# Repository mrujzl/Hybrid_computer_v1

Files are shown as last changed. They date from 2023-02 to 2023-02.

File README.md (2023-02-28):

# Hybrid_computer_v1
Hybrid computer for study of nonlinear dynamic systems. It was developed at Department of Radio Electronics, Brno University of Technology within the grant Development of analog computer with hybrid analog-digital components for accurate modeling of chaotic systems. This grant is realised within the project Quality Internal Grants of BUT (KInG BUT), Reg. No. CZ.02.2.69 / 0.0 / 0.0 / 19_073 / 0016948, which is financed from the OP RDE.

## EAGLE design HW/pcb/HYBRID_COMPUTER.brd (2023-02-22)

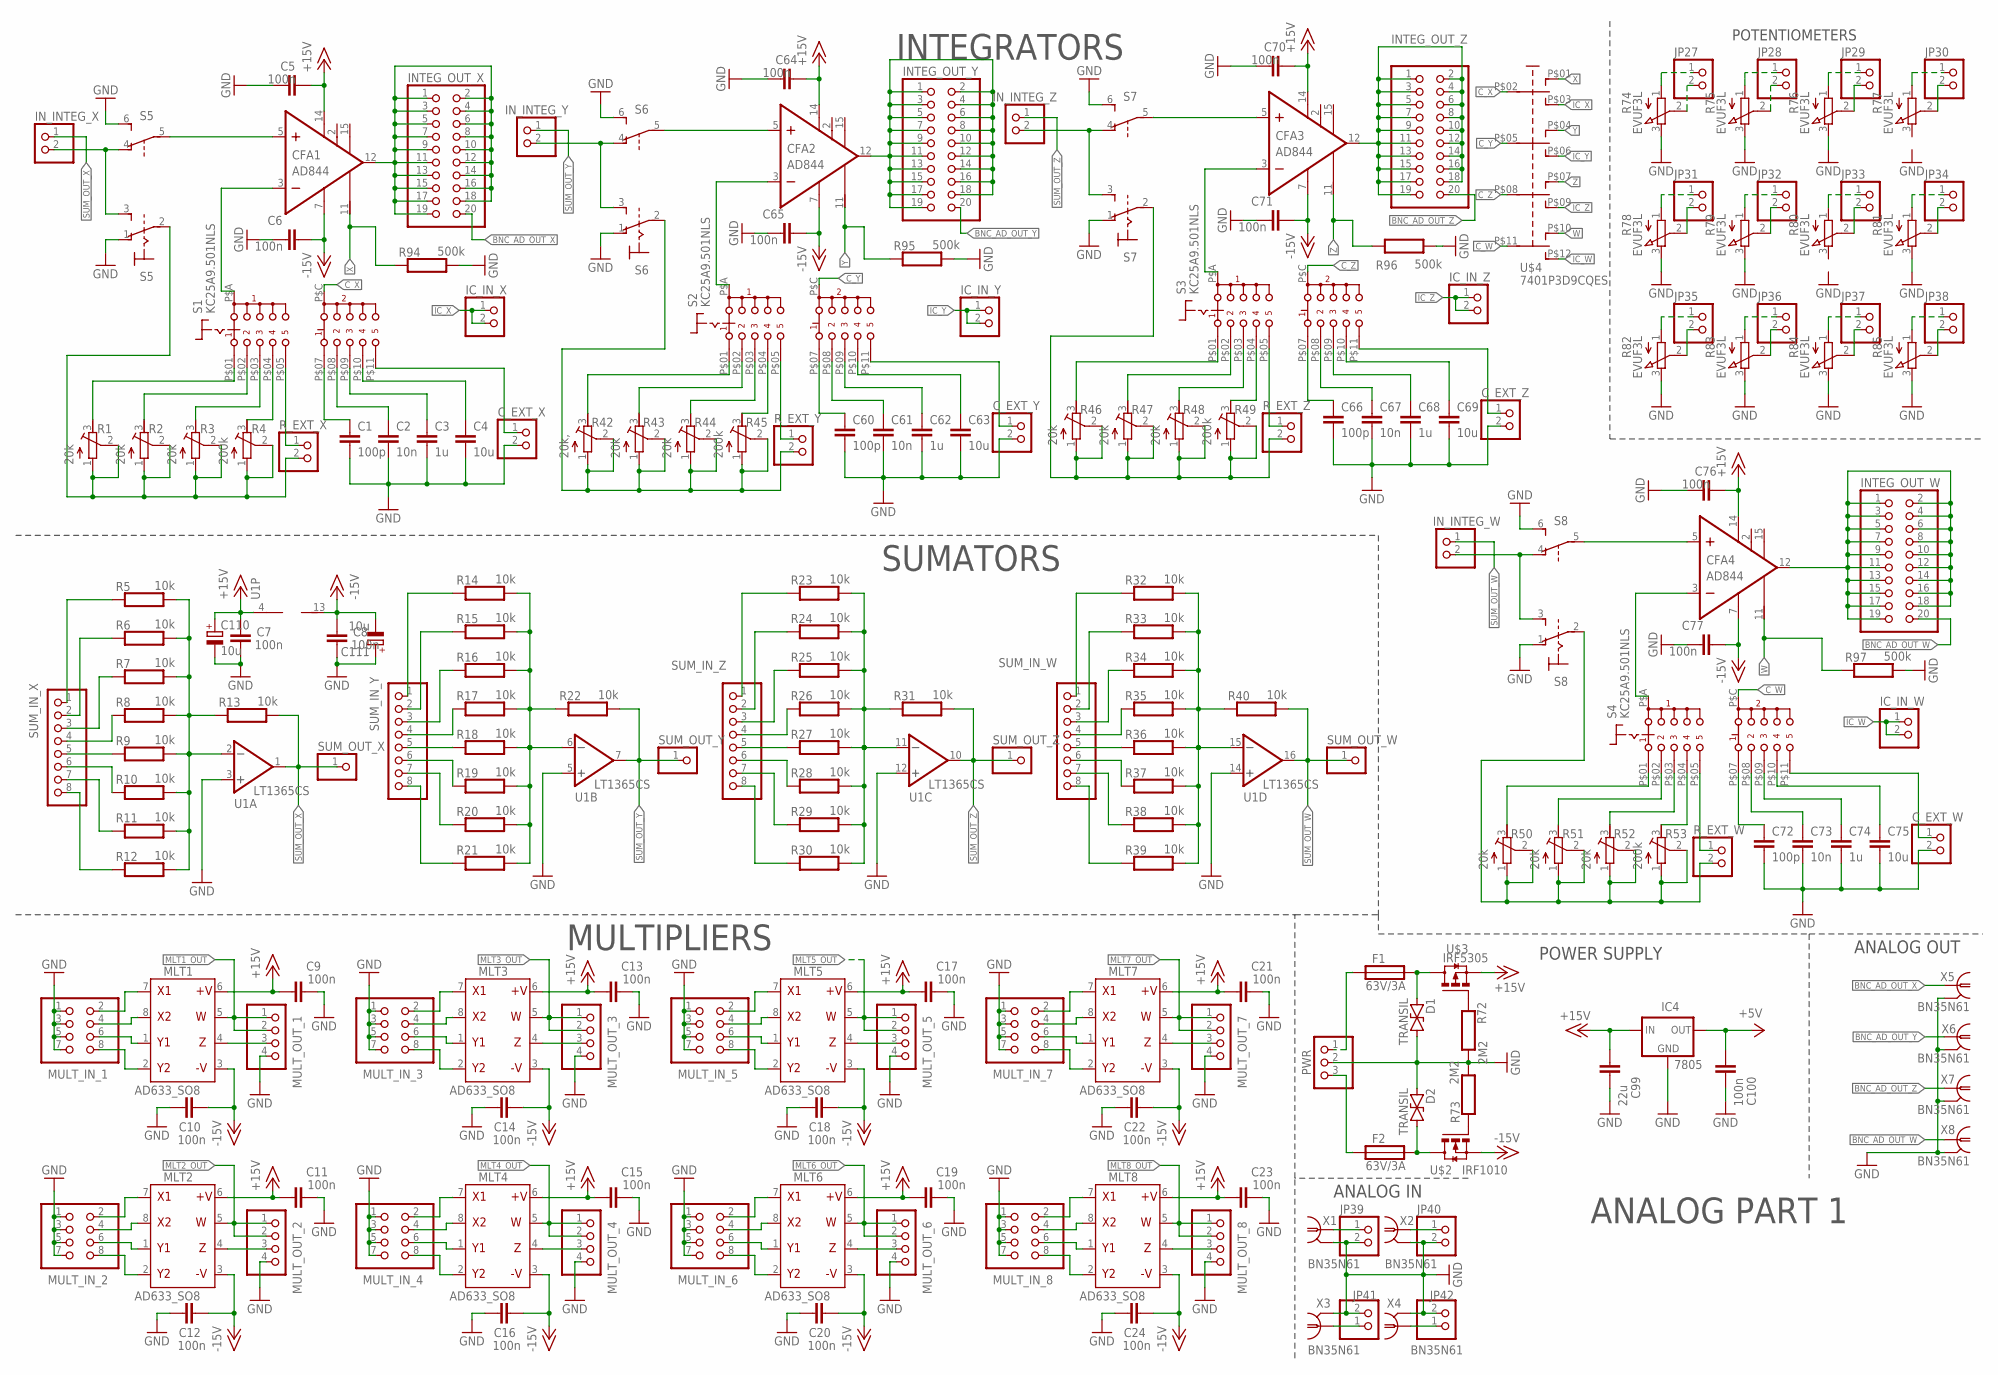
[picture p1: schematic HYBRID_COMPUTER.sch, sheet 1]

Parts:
C1, C60, C66, C72: 100p; C_1206
C2, C61, C67, C73: 10n; C_1206
C3, C62, C68, C74: 1u; C_1206
C4, C63, C69, C75: 10u; C_1206
C5, C6, C7, C8, C9, C10, C11, C12, C13, C14, C15, C16, C17, C18, C19, C20, C21, C22, C23, C24, C64, C65, C70, C71, C76, C77, C100: 100n; C_1206
C99: 22u; C_1206
C110, C111: 10u; E2,5-5
CFA1, CFA2, CFA3, CFA4: AD844; SOIC16R
C_EXT_W: PINHD-1X2; 1X02
C_EXT_X: PINHD-1X2; 1X02
C_EXT_Y: PINHD-1X2; 1X02
C_EXT_Z: PINHD-1X2; 1X02
D1, D2: TRANSIL; DO15-12
F1, F2: 63V/3A; FUSE_1206
IC4: 7805; 78MXXS
IC_IN_W: PINHD-1X2; 1X02
IC_IN_X: PINHD-1X2; 1X02
IC_IN_Y: PINHD-1X2; 1X02
IC_IN_Z: PINHD-1X2; 1X02
INTEG_OUT_W: PINHD-2X10; 2X10
INTEG_OUT_X: PINHD-2X10; 2X10
INTEG_OUT_Y: PINHD-2X10; 2X10
INTEG_OUT_Z: PINHD-2X10; 2X10
IN_INTEG_W: PINHD-1X2; 1X02
IN_INTEG_X: PINHD-1X2; 1X02
IN_INTEG_Y: PINHD-1X2; 1X02
IN_INTEG_Z: PINHD-1X2; 1X02
JP27, JP28, JP29, JP30, JP31, JP32, JP33, JP34, JP35, JP36, JP37, JP38, JP39, JP40, JP41, JP42: PINHD-1X2; 1X02
MLT1, MLT2, MLT3, MLT4, MLT5, MLT6, MLT7, MLT8: AD633_SO8; SO8
MULT_IN_1, MULT_IN_2, MULT_IN_3, MULT_IN_4, MULT_IN_5, MULT_IN_6, MULT_IN_7, MULT_IN_8: PINHD-2X4; 2X04
MULT_OUT_1, MULT_OUT_2, MULT_OUT_3, MULT_OUT_4, MULT_OUT_5, MULT_OUT_6, MULT_OUT_7, MULT_OUT_8: PINHD-1X4; 1X04
PWR: PINHD-1X3; 1X03
R1, R2, R3, R43, R44, R46, R47, R48, R50, R51, R52: 20k; RTRIM64W
R4, R45, R49, R53: 200k; RTRIM64W
R5, R6, R7, R8, R9, R10, R11, R12, R13, R14, R15, R16, R17, R18, R19, R20, R21, R22, R23, R24, R25, R26, R27, R28, R29, R30, R31, R32, R33, R34, R35, R36, R37, R38, R39, R40: 10k; R_1206
R42: 20k,; RTRIM64W
R72, R73: 2M2; R_1206
R74, R75, R76, R77, R78, R79, R80, R81, R82, R83, R84, R85: EVUF3L; EVUFXL
R94, R95, R96, R97: 500k; R_1206
R_EXT_W: PINHD-1X2; 1X02
R_EXT_X: PINHD-1X2; 1X02
R_EXT_Y: PINHD-1X2; 1X02
R_EXT_Z: PINHD-1X2; 1X02
S1, S2, S3, S4: KC25A9.501NLS
S5, S6, S7, S8: 320-938
SUM_IN_W: PINHD-1X8; 1X08
SUM_IN_X: PINHD-1X8; 1X08
SUM_IN_Y: PINHD-1X8; 1X08
SUM_IN_Z: PINHD-1X8; 1X08
SUM_OUT_W: PINHD-1X1; 1X01
SUM_OUT_X: PINHD-1X1; 1X01
SUM_OUT_Y: PINHD-1X1; 1X01
SUM_OUT_Z: PINHD-1X1; 1X01
U1: LT1365CS; SO16
U$2: IRF1010; TO220BV
U$3: IRF5305; TO220BV
U$4: 7401P3D9CQES
X1, X2, X3, X4, X5, X6, X7, X8: BN35N61; B35N61

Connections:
+5V: C100.1, IC4.OUT; also elsewhere on the board
+15V: C5.1, C7.1, C9.1, C11.1, C13.1, C15.1, C17.1, C19.1, C21.1, C23.1, C64.1, C70.1, C76.1, C99.1, C110.+, CFA1.14 (7), CFA2.14 (7), CFA3.14 (7), CFA4.14 (7), IC4.IN, MLT1.6 (8), MLT2.6 (8), MLT3.6 (8), MLT4.6 (8), MLT5.6 (8), MLT6.6 (8), MLT7.6 (8), MLT8.6 (8), U1.4 (V+), U$3.S; also elsewhere on the board
-15V: C6.1, C8.1, C10.1, C12.1, C14.1, C16.1, C18.1, C20.1, C22.1, C24.1, C65.1, C71.1, C77.1, C111.-, CFA1.7 (4), CFA2.7 (4), CFA3.7 (4), CFA4.7 (4), MLT1.3 (5), MLT2.3 (5), MLT3.3 (5), MLT4.3 (5), MLT5.3 (5), MLT6.3 (5), MLT7.3 (5), MLT8.3 (5), U1.13 (V-), U$2.S; also elsewhere on the board
BNC_AD_OUT_W: INTEG_OUT_W.20, X8.1; also elsewhere on the board
BNC_AD_OUT_X: INTEG_OUT_X.20, X5.1; also elsewhere on the board
BNC_AD_OUT_Y: INTEG_OUT_Y.20, X6.1; also elsewhere on the board
BNC_AD_OUT_Z: INTEG_OUT_Z.20, X7.1; also elsewhere on the board
C_W: S4.P$C (C), U$4.P$11 (11)
C_X: S1.P$C (C), U$4.P$02 (2)
C_Y: S2.P$C (C), U$4.P$05 (5)
C_Z: S3.P$C (C), U$4.P$08 (8)
GND: C1.2, C2.2, C3.2, C4.2, C5.2, C6.2, C7.2, C8.2, C9.2, C10.2, C11.2, C12.2, C13.2, C14.2, C15.2, C16.2, C17.2, C18.2, C19.2, C20.2, C21.2, C22.2, C23.2, C24.2, C60.2, C61.2, C62.2, C63.2, C64.2, C65.2, C66.2, C67.2, C68.2, C69.2, C70.2, C71.2, C72.2, C73.2, C74.2, C75.2, C76.2, C77.2, C99.2, C100.2, C110.-, C111.+, C_EXT_W.2, C_EXT_X.2, C_EXT_Y.2, C_EXT_Z.2, D1.C, D2.A, IC4.GND, JP39.2, JP40.2, JP41.2, JP42.2, MULT_IN_1.1, MULT_IN_1.3, MULT_IN_1.5, MULT_IN_1.7, MULT_IN_2.1, MULT_IN_2.3, MULT_IN_2.5, MULT_IN_2.7, MULT_IN_3.1, MULT_IN_3.3, MULT_IN_3.5, MULT_IN_3.7, MULT_IN_4.1, MULT_IN_4.3, MULT_IN_4.5, MULT_IN_4.7, MULT_IN_5.1, MULT_IN_5.3, MULT_IN_5.5, MULT_IN_5.7, MULT_IN_6.1, MULT_IN_6.3, MULT_IN_6.5, MULT_IN_6.7, MULT_IN_7.1, MULT_IN_7.3, MULT_IN_7.5, MULT_IN_7.7, MULT_IN_8.1, MULT_IN_8.3, MULT_IN_8.5, MULT_IN_8.7, MULT_OUT_1.4, MULT_OUT_2.4, MULT_OUT_3.4, MULT_OUT_4.4, MULT_OUT_5.4, MULT_OUT_6.4, MULT_OUT_7.4, MULT_OUT_8.4, PWR.2, R72.2, R73.2, R74.3 (E), R75.3 (E), R76.3 (E), R78.3 (E), R79.3 (E), R81.3 (E), R82.3 (E), R83.3 (E), R84.3 (E), R85.3 (E), R94.2, R95.2, R96.2, R97.2, S5.1 (O), S5.6 (S), S6.1 (O), S6.6 (S), S7.1 (O), S7.6 (S), S8.1 (O), S8.6 (S), U1.3 (+IN), U1.5 (+IN), U1.12 (+IN), U1.14 (+IN), X1.2, X1.3 (2), X1.4 (2), X1.5 (2), X2.2, X2.3 (2), X2.4 (2), X2.5 (2), X3.2, X3.3 (2), X3.4 (2), X3.5 (2), X4.2, X4.3 (2), X4.4 (2), X4.5 (2), X5.2, X5.3 (2), X5.4 (2), X5.5 (2), X6.2, X6.3 (2), X6.4 (2), X6.5 (2), X7.2, X7.3 (2), X7.4 (2), X7.5 (2), X8.2, X8.3 (2), X8.4 (2), X8.5 (2); also elsewhere on the board
IC_W: IC_IN_W.1, IC_IN_W.2, U$4.P$12 (12)
IC_X: IC_IN_X.1, IC_IN_X.2, U$4.P$03 (3)
IC_Y: IC_IN_Y.1, IC_IN_Y.2, U$4.P$06 (6)
IC_Z: IC_IN_Z.1, IC_IN_Z.2, U$4.P$09 (9)
INTEG_OUT_W: CFA4.12 (6), INTEG_OUT_W.1, INTEG_OUT_W.2, INTEG_OUT_W.3, INTEG_OUT_W.4, INTEG_OUT_W.5, INTEG_OUT_W.6, INTEG_OUT_W.7, INTEG_OUT_W.8, INTEG_OUT_W.9, INTEG_OUT_W.10, INTEG_OUT_W.11, INTEG_OUT_W.12, INTEG_OUT_W.13, INTEG_OUT_W.14, INTEG_OUT_W.15, INTEG_OUT_W.16, INTEG_OUT_W.17, INTEG_OUT_W.18, INTEG_OUT_W.19
INTEG_OUT_Y: CFA2.12 (6), INTEG_OUT_Y.1, INTEG_OUT_Y.2, INTEG_OUT_Y.3, INTEG_OUT_Y.4, INTEG_OUT_Y.5, INTEG_OUT_Y.6, INTEG_OUT_Y.7, INTEG_OUT_Y.8, INTEG_OUT_Y.9, INTEG_OUT_Y.10, INTEG_OUT_Y.11, INTEG_OUT_Y.12, INTEG_OUT_Y.13, INTEG_OUT_Y.14, INTEG_OUT_Y.15, INTEG_OUT_Y.16, INTEG_OUT_Y.17, INTEG_OUT_Y.18, INTEG_OUT_Y.19
INTEG_OUT_Z: CFA3.12 (6), INTEG_OUT_Z.1, INTEG_OUT_Z.2, INTEG_OUT_Z.3, INTEG_OUT_Z.4, INTEG_OUT_Z.5, INTEG_OUT_Z.6, INTEG_OUT_Z.7, INTEG_OUT_Z.8, INTEG_OUT_Z.9, INTEG_OUT_Z.10, INTEG_OUT_Z.11, INTEG_OUT_Z.12, INTEG_OUT_Z.13, INTEG_OUT_Z.14, INTEG_OUT_Z.15, INTEG_OUT_Z.16, INTEG_OUT_Z.17, INTEG_OUT_Z.18, INTEG_OUT_Z.19
MLT1_OUT: MLT1.5 (7), MULT_OUT_1.1, MULT_OUT_1.2
MLT2_OUT: MLT2.5 (7), MULT_OUT_2.1, MULT_OUT_2.2
MLT3_OUT: MLT3.5 (7), MULT_OUT_3.1, MULT_OUT_3.2
MLT4_OUT: MLT4.5 (7), MULT_OUT_4.1, MULT_OUT_4.2
MLT5_OUT: MLT5.5 (7), MULT_OUT_5.1, MULT_OUT_5.2
MLT6_OUT: MLT6.5 (7), MULT_OUT_6.1, MULT_OUT_6.2
MLT7_OUT: MLT7.5 (7), MULT_OUT_7.1, MULT_OUT_7.2
MLT8_OUT: MLT8.5 (7), MULT_OUT_8.1, MULT_OUT_8.2
unnamed: R1.1 (A), R1.2 (S), R2.1 (A), R2.2 (S), R3.1 (A), R3.2 (S), R4.1 (A), R4.2 (S), R_EXT_X.2, S5.2
unnamed: CFA1.5 (3), S5.5
unnamed: CFA1.3 (2), S1.P$A (A)
unnamed: IN_INTEG_X.2, S5.3 (S), S5.4 (O)
unnamed: R4.3 (E), S1.P$04 (4)
unnamed: R1.3 (E), S1.P$01 (1)
unnamed: R2.3 (E), S1.P$02 (2)
unnamed: R3.3 (E), S1.P$03 (3)
unnamed: C1.1, S1.P$07 (7)
unnamed: R5.2, R6.2, R7.2, R8.2, R9.2, R10.2, R11.2, R12.2, R13.1, U1.2 (-IN)
unnamed: C4.1, S1.P$10 (10)
unnamed: C3.1, S1.P$09 (9)
unnamed: C2.1, S1.P$08 (8)
unnamed: R_EXT_X.1, S1.P$05 (5)
unnamed: R9.1, SUM_IN_X.5
unnamed: C_EXT_X.1, S1.P$11 (11)
unnamed: R10.1, SUM_IN_X.6
unnamed: R11.1, SUM_IN_X.7
unnamed: R12.1, SUM_IN_X.8
unnamed: R8.1, SUM_IN_X.4
unnamed: R7.1, SUM_IN_X.3
unnamed: R6.1, SUM_IN_X.2
unnamed: R5.1, SUM_IN_X.1
unnamed: R14.2, R15.2, R16.2, R17.2, R18.2, R19.2, R20.2, R21.2, R22.1, U1.6 (-IN)
unnamed: JP29.2, R76.2 (S)
unnamed: R18.1, SUM_IN_Y.5
unnamed: R19.1, SUM_IN_Y.6
unnamed: R20.1, SUM_IN_Y.7
unnamed: R21.1, SUM_IN_Y.8
unnamed: R17.1, SUM_IN_Y.4
unnamed: R16.1, SUM_IN_Y.3
unnamed: R15.1, SUM_IN_Y.2
unnamed: R14.1, SUM_IN_Y.1
unnamed: R23.2, R24.2, R25.2, R26.2, R27.2, R28.2, R29.2, R30.2, R31.1, U1.11 (-IN)
unnamed: MLT1.7 (1), MULT_IN_1.2
unnamed: R27.1, SUM_IN_Z.5
unnamed: R28.1, SUM_IN_Z.6
unnamed: R29.1, SUM_IN_Z.7
unnamed: R30.1, SUM_IN_Z.8
unnamed: R26.1, SUM_IN_Z.4
unnamed: R25.1, SUM_IN_Z.3
unnamed: R24.1, SUM_IN_Z.2
unnamed: R23.1, SUM_IN_Z.1
unnamed: R32.2, R33.2, R34.2, R35.2, R36.2, R37.2, R38.2, R39.2, R40.1, U1.15 (-IN)
unnamed: R36.1, SUM_IN_W.5
unnamed: R37.1, SUM_IN_W.6
unnamed: R38.1, SUM_IN_W.7
unnamed: R39.1, SUM_IN_W.8
unnamed: R35.1, SUM_IN_W.4
unnamed: R34.1, SUM_IN_W.3
unnamed: R33.1, SUM_IN_W.2
unnamed: R32.1, SUM_IN_W.1
unnamed: MLT1.4 (6), MULT_OUT_1.3
unnamed: MLT1.8 (2), MULT_IN_1.4
unnamed: MLT1.1 (3), MULT_IN_1.6
unnamed: MLT1.2 (4), MULT_IN_1.8
unnamed: MLT2.4 (6), MULT_OUT_2.3
unnamed: MLT2.7 (1), MULT_IN_2.2
unnamed: MLT2.8 (2), MULT_IN_2.4
unnamed: MLT2.1 (3), MULT_IN_2.6
unnamed: MLT2.2 (4), MULT_IN_2.8
unnamed: MLT3.4 (6), MULT_OUT_3.3
unnamed: MLT3.7 (1), MULT_IN_3.2
unnamed: MLT3.8 (2), MULT_IN_3.4
unnamed: MLT3.1 (3), MULT_IN_3.6
unnamed: MLT3.2 (4), MULT_IN_3.8
unnamed: R46.1 (A), R46.2 (S), R47.1 (A), R47.2 (S), R48.1 (A), R48.2 (S), R49.1 (A), R49.2 (S), R_EXT_Z.2, S7.2
unnamed: MLT4.4 (6), MULT_OUT_4.3
unnamed: MLT4.7 (1), MULT_IN_4.2
unnamed: MLT4.8 (2), MULT_IN_4.4
unnamed: MLT4.1 (3), MULT_IN_4.6
unnamed: MLT4.2 (4), MULT_IN_4.8
unnamed: MLT5.4 (6), MULT_OUT_5.3
unnamed: MLT5.7 (1), MULT_IN_5.2
unnamed: MLT5.8 (2), MULT_IN_5.4
unnamed: MLT5.1 (3), MULT_IN_5.6
unnamed: MLT5.2 (4), MULT_IN_5.8
unnamed: MLT6.4 (6), MULT_OUT_6.3
unnamed: MLT6.7 (1), MULT_IN_6.2
unnamed: MLT6.8 (2), MULT_IN_6.4
unnamed: MLT6.1 (3), MULT_IN_6.6
unnamed: MLT6.2 (4), MULT_IN_6.8
unnamed: MLT7.4 (6), MULT_OUT_7.3
unnamed: MLT7.7 (1), MULT_IN_7.2
unnamed: MLT7.8 (2), MULT_IN_7.4
unnamed: MLT7.1 (3), MULT_IN_7.6
unnamed: MLT7.2 (4), MULT_IN_7.8
unnamed: MLT8.4 (6), MULT_OUT_8.3
unnamed: MLT8.7 (1), MULT_IN_8.2
unnamed: MLT8.8 (2), MULT_IN_8.4
unnamed: MLT8.1 (3), MULT_IN_8.6
unnamed: MLT8.2 (4), MULT_IN_8.8
unnamed: JP27.1, R74.1 (A)
unnamed: JP27.2, R74.2 (S)
unnamed: JP28.2, R75.2 (S)
unnamed: JP28.1, R75.1 (A)
unnamed: JP29.1, R76.1 (A)
unnamed: JP30.1, R77.1 (A)
unnamed: JP30.2, R77.2 (S)
unnamed: JP34.1, R81.1 (A)
unnamed: JP34.2, R81.2 (S)
unnamed: JP33.2, R80.2 (S)
unnamed: JP33.1, R80.1 (A)
unnamed: JP32.1, R79.1 (A)
unnamed: JP32.2, R79.2 (S)
unnamed: JP31.1, R78.1 (A)
unnamed: JP31.2, R78.2 (S)
unnamed: JP35.1, R82.1 (A)
unnamed: JP35.2, R82.2 (S)
unnamed: JP36.1, R83.1 (A)
unnamed: JP36.2, R83.2 (S)
unnamed: JP37.1, R84.1 (A)
unnamed: JP37.2, R84.2 (S)
unnamed: JP38.1, R85.1 (A)
unnamed: JP38.2, R85.2 (S)
unnamed: D1.A, F1.2, U$3.D
unnamed: R42.1 (A), R42.2 (S), R43.1 (A), R43.2 (S), R44.1 (A), R44.2 (S), R45.1 (A), R45.2 (S), R_EXT_Y.2, S6.2
unnamed: CFA2.5 (3), S6.5
unnamed: CFA2.3 (2), S2.P$A (A)
unnamed: IN_INTEG_Y.2, S6.3 (S), S6.4 (O)
unnamed: R42.3 (E), S2.P$01 (1)
unnamed: R43.3 (E), S2.P$02 (2)
unnamed: R44.3 (E), S2.P$03 (3)
unnamed: C63.1, S2.P$10 (10)
unnamed: C62.1, S2.P$09 (9)
unnamed: C61.1, S2.P$08 (8)
unnamed: CFA1.12 (6), INTEG_OUT_X.1, INTEG_OUT_X.2, INTEG_OUT_X.3, INTEG_OUT_X.4, INTEG_OUT_X.5, INTEG_OUT_X.6, INTEG_OUT_X.7, INTEG_OUT_X.8, INTEG_OUT_X.9, INTEG_OUT_X.10, INTEG_OUT_X.11, INTEG_OUT_X.12, INTEG_OUT_X.13, INTEG_OUT_X.14, INTEG_OUT_X.15, INTEG_OUT_X.16, INTEG_OUT_X.17, INTEG_OUT_X.18, INTEG_OUT_X.19
unnamed: R45.3 (E), S2.P$04 (4)
unnamed: C60.1, S2.P$07 (7)
unnamed: R_EXT_Y.1, S2.P$05 (5)
unnamed: C_EXT_Y.1, S2.P$11 (11)
unnamed: CFA3.5 (3), S7.5
unnamed: CFA3.3 (2), S3.P$A (A)
unnamed: IN_INTEG_Z.2, S7.3 (S), S7.4 (O)
unnamed: R46.3 (E), S3.P$01 (1)
unnamed: R47.3 (E), S3.P$02 (2)
unnamed: R48.3 (E), S3.P$03 (3)
unnamed: C69.1, S3.P$10 (10)
unnamed: C68.1, S3.P$09 (9)
unnamed: C67.1, S3.P$08 (8)
unnamed: R49.3 (E), S3.P$04 (4)
unnamed: C66.1, S3.P$07 (7)
unnamed: R_EXT_Z.1, S3.P$05 (5)
unnamed: C_EXT_Z.1, S3.P$11 (11)
unnamed: R50.1 (A), R50.2 (S), R51.1 (A), R51.2 (S), R52.1 (A), R52.2 (S), R53.1 (A), R53.2 (S), R_EXT_W.2, S8.2
unnamed: CFA4.5 (3), S8.5
unnamed: CFA4.3 (2), S4.P$A (A)
unnamed: IN_INTEG_W.2, S8.3 (S), S8.4 (O)
unnamed: R50.3 (E), S4.P$01 (1)
unnamed: R51.3 (E), S4.P$02 (2)
unnamed: R52.3 (E), S4.P$03 (3)
unnamed: C75.1, S4.P$10 (10)
unnamed: C74.1, S4.P$09 (9)
unnamed: C73.1, S4.P$08 (8)
unnamed: R53.3 (E), S4.P$04 (4)
unnamed: C72.1, S4.P$07 (7)
unnamed: R_EXT_W.1, S4.P$05 (5)
unnamed: C_EXT_W.1, S4.P$11 (11)
unnamed: F2.1, PWR.3
unnamed: F1.1, PWR.1
unnamed: JP39.1, X1.1
unnamed: JP40.1, X2.1
unnamed: JP41.1, X3.1
unnamed: JP42.1, X4.1
unnamed: D2.C, F2.2, U$2.D
unnamed: R72.1, U$3.G
unnamed: R73.1, U$2.G
SUM_OUT_W: IN_INTEG_W.1, R40.2, SUM_OUT_W.1, U1.16 (OUT)
SUM_OUT_X: IN_INTEG_X.1, R13.2, SUM_OUT_X.1, U1.1 (OUT)
SUM_OUT_Y: IN_INTEG_Y.1, R22.2, SUM_OUT_Y.1, U1.7 (OUT)
SUM_OUT_Z: IN_INTEG_Z.1, R31.2, SUM_OUT_Z.1, U1.10 (OUT)
W: CFA4.11 (5), R97.1, U$4.P$10 (10)
X: CFA1.11 (5), R94.1, U$4.P$01 (1)
Y: CFA2.11 (5), R95.1, U$4.P$04 (4)
Z: CFA3.11 (5), R96.1, U$4.P$07 (7)

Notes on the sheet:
ANALOG PART 1
INTEGRATORS
ANALOG OUT
SUMATORS
POWER SUPPLY
MULTIPLIERS
POTENTIOMETERS
ANALOG IN

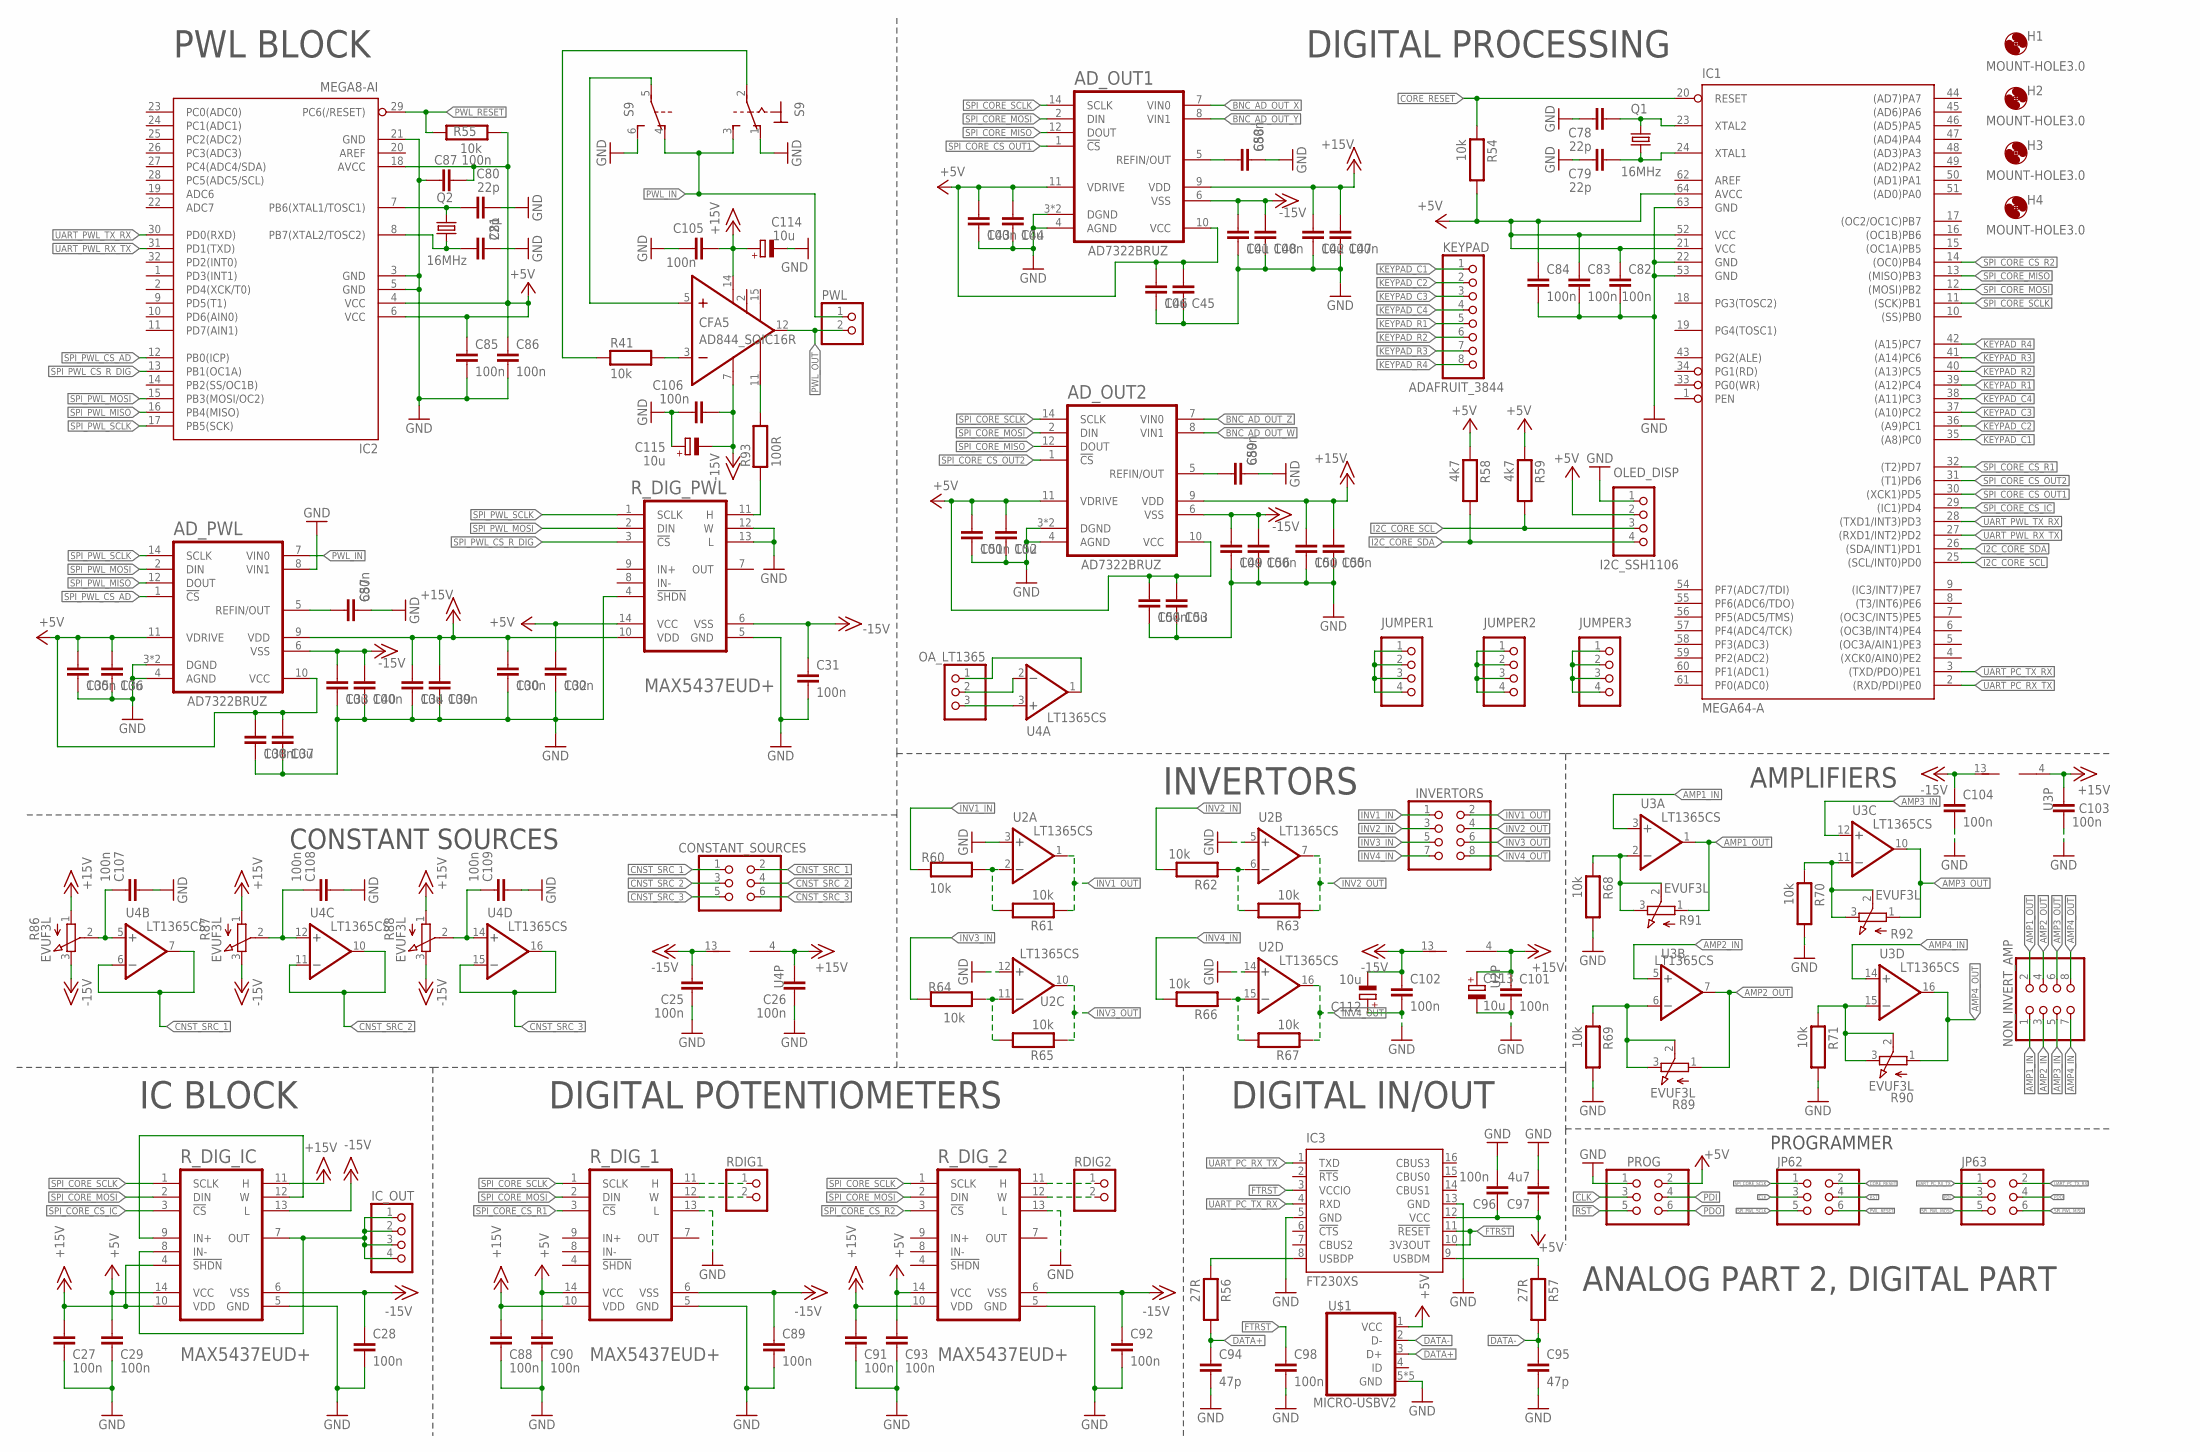
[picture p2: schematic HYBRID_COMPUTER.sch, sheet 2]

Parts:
AD_OUT1, AD_OUT2: AD7322; TSSOP-14
AD_PWL: AD7322; TSSOP-14
C25, C26, C27, C28, C29, C30, C31, C32, C35, C38, C39, C40, C43, C47, C48, C51, C54, C55, C56, C82, C83, C84, C85, C86, C87, C88, C89, C90, C91, C92, C93, C96, C98, C101, C102, C103, C104, C105, C106, C107, C108, C109: 100n; C_1206
C33, C34, C36, C37, C41, C42, C44, C46, C49, C50, C52, C53: 10u; C_1206
C45: C_1206
C57, C58, C59: 680n; C_1206
C78, C79, C80, C81: 22p; C_1206
C94, C95: 47p; C_1206
C97: 4u7; C_1206
C112, C113, C114, C115: 10u; E2,5-5
CFA5: AD844_SOIC16R; SOIC16R
CONSTANT_SOURCES: PINHD-2X3; 2X03
H1, H2, H3, H4: MOUNT-HOLE3.0; 3,0
IC1: MEGA64-A; TQFP64
IC2: MEGA8-AI; TQFP32-08
IC3: FT230XS; SSOP16
IC_OUT: PINHD-1X4; 1X04
INVERTORS: PINHD-2X4; 2X04
JP62, JP63: PINHD-2X3; 2X03
JUMPER1, JUMPER2, JUMPER3: PINHD-1X4; 1X04
KEYPAD: ADAFRUIT_3844; 1X08
NON_INVERT_AMP: PINHD-2X4; 2X04
OA_LT1365: PINHD-1X3; 1X03
OLED_DISP: I2C_SSH1106; 1X04
PROG: PINHD-2X3; 2X03
PWL: PINHD-1X2; 1X02
Q1, Q2: 16MHz; HC49/S
R41, R54, R55, R60, R61, R62, R63, R64, R65, R66, R67, R68, R69, R70, R71: 10k; R_1206
R56, R57: 27R; R_1206
R58, R59: 4k7; R_1206
R86, R87, R88, R89, R90, R91, R92: EVUF3L; EVUFXL
R93: 100R; R_1206
RDIG1, RDIG2: PINHD-1X2; 1X02
R_DIG_1, R_DIG_2: MAXIM_MAX5437EUD+MAXIM_MAX5437EUD+_0_0; MAXIM_MAX5437EUD+_0
R_DIG_IC: MAXIM_MAX5437EUD+MAXIM_MAX5437EUD+_0_0; MAXIM_MAX5437EUD+_0
R_DIG_PWL: MAXIM_MAX5437EUD+MAXIM_MAX5437EUD+_0_0; MAXIM_MAX5437EUD+_0
S9: 320-938
U2, U3, U4: LT1365CS; SO16
U$1: MICRO-USBV2; MICRO-USB-2

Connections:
+5V: AD_OUT1.10 (VCC), AD_OUT1.11 (VDRIVE), AD_OUT2.10 (VCC), AD_OUT2.11 (VDRIVE), AD_PWL.10 (VCC), AD_PWL.11 (VDRIVE), C29.1, C32.1, C35.1, C36.1, C37.1, C38.1, C43.1, C44.1, C45.1, C46.1, C51.1, C52.1, C53.1, C54.1, C82.1, C83.1, C84.1, C85.1, C86.1, C87.1, C90.1, C93.1, C96.1, C97.1, IC1.21 (VCC), IC1.52 (VCC), IC1.64 (AVCC), IC2.4 (VCC), IC2.6 (VCC), IC2.18 (AVCC), IC3.12 (VCC), OLED_DISP.2, PROG.2, R54.2, R55.2, R58.1, R59.1, R_DIG_1.14 (VCC), R_DIG_2.14 (VCC), R_DIG_IC.14 (VCC), R_DIG_PWL.14 (VCC), U$1.1 (VCC); also elsewhere on the board
+15V: AD_OUT1.9 (VDD), AD_OUT2.9 (VDD), AD_PWL.9 (VDD), C26.2, C27.1, C30.1, C34.1, C39.1, C42.1, C47.1, C50.1, C55.1, C88.1, C91.1, C101.1, C103.1, C105.1, C113.+, C114.+, CFA5.14 (7), R86.1 (A), R87.1 (A), R88.1 (A), R_DIG_1.10 (VDD), R_DIG_2.10 (VDD), R_DIG_IC.4 (!SHDN!), R_DIG_IC.10 (VDD), R_DIG_IC.11 (H), R_DIG_PWL.10 (VDD), U2.4 (V+), U3.4 (V+), U4.4 (V+); also elsewhere on the board
-15V: AD_OUT1.6 (VSS), AD_OUT2.6 (VSS), AD_PWL.6 (VSS), C25.2, C28.1, C31.1, C33.1, C40.1, C41.1, C48.1, C49.1, C56.1, C89.1, C92.1, C102.1, C104.1, C106.1, C112.-, C115.-, CFA5.7 (4), R86.3 (E), R87.3 (E), R88.3 (E), R_DIG_1.6 (VSS), R_DIG_2.6 (VSS), R_DIG_IC.6 (VSS), R_DIG_IC.13 (L), R_DIG_PWL.6 (VSS), U2.13 (V-), U3.13 (V-), U4.13 (V-); also elsewhere on the board
AMP1_IN: NON_INVERT_AMP.1, U3.3 (+IN)
AMP1_OUT: NON_INVERT_AMP.2, R91.1 (A), U3.1 (OUT)
AMP2_IN: NON_INVERT_AMP.3, U3.5 (+IN)
AMP2_OUT: NON_INVERT_AMP.4, R89.1 (A), U3.7 (OUT)
AMP3_IN: NON_INVERT_AMP.5, U3.12 (+IN)
AMP3_OUT: NON_INVERT_AMP.6, R92.1 (A), U3.10 (OUT)
AMP4_IN: NON_INVERT_AMP.7, U3.14 (+IN)
AMP4_OUT: NON_INVERT_AMP.8, R90.1 (A), U3.16 (OUT)
BNC_AD_OUT_W: AD_OUT2.8 (VIN1); also elsewhere on the board
BNC_AD_OUT_X: AD_OUT1.7 (VIN0); also elsewhere on the board
BNC_AD_OUT_Y: AD_OUT1.8 (VIN1); also elsewhere on the board
BNC_AD_OUT_Z: AD_OUT2.7 (VIN0); also elsewhere on the board
CLK: JP62.3, PROG.3
CNST_SRC_1: CONSTANT_SOURCES.1, CONSTANT_SOURCES.2, U4.6 (-IN), U4.7 (OUT)
CNST_SRC_2: CONSTANT_SOURCES.3, CONSTANT_SOURCES.4, U4.10 (OUT), U4.11 (-IN)
CNST_SRC_3: CONSTANT_SOURCES.5, CONSTANT_SOURCES.6, U4.15 (-IN), U4.16 (OUT)
CORE_RESET: IC1.20 (RESET), JP62.2, R54.1
DATA+: C94.1, R56.2, U$1.3 (D+)
DATA-: C95.1, R57.2, U$1.2 (D-)
FTRST: C98.1, IC3.3 (VCCIO), IC3.10 (3V3OUT), IC3.11 (!RESET)
GND: AD_OUT1.3 (DGND), AD_OUT1.4 (AGND), AD_OUT1.13 (DGND), AD_OUT2.3 (DGND), AD_OUT2.4 (AGND), AD_OUT2.13 (DGND), AD_PWL.3 (DGND), AD_PWL.4 (AGND), AD_PWL.8 (VIN1), AD_PWL.13 (DGND), C25.1, C26.1, C27.2, C28.2, C29.2, C30.2, C31.2, C32.2, C33.2, C34.2, C35.2, C36.2, C37.2, C38.2, C39.2, C40.2, C41.2, C42.2, C43.2, C44.2, C45.2, C46.2, C47.2, C48.2, C49.2, C50.2, C51.2, C52.2, C53.2, C54.2, C55.2, C56.2, C57.2, C58.2, C59.2, C78.1, C79.1, C80.2, C81.2, C82.2, C83.2, C84.2, C85.2, C86.2, C87.2, C88.2, C89.2, C90.2, C91.2, C92.2, C93.2, C94.2, C95.2, C96.2, C97.2, C98.2, C101.2, C102.2, C103.2, C104.2, C105.2, C106.2, C107.2, C108.2, C109.2, C112.+, C113.-, C114.-, C115.+, IC1.22 (GND), IC1.53 (GND), IC1.63 (GND), IC2.3 (GND), IC2.5 (GND), IC2.21 (GND), IC3.5 (GND), IC3.13 (GND), OLED_DISP.1, PROG.1, R68.2, R69.2, R70.2, R71.2, R_DIG_1.5 (GND), R_DIG_1.13 (L), R_DIG_2.5 (GND), R_DIG_2.13 (L), R_DIG_IC.5 (GND), R_DIG_PWL.4 (!SHDN!), R_DIG_PWL.5 (GND), R_DIG_PWL.12 (W), R_DIG_PWL.13 (L), S9.1 (O), S9.6 (S), U2.3 (+IN), U2.5 (+IN), U2.12 (+IN), U2.14 (+IN), U$1.5 (GND), U$1.P$1 (GND), U$1.P$2 (GND), U$1.P$3 (GND), U$1.P$4 (GND); also elsewhere on the board
I2C_CORE_SCL: IC1.25 ((SCL/INT0)PD0), OLED_DISP.3, R59.2
I2C_CORE_SDA: IC1.26 ((SDA/INT1)PD1), OLED_DISP.4, R58.2
INV1_IN: INVERTORS.1, R60.2
INV1_OUT: INVERTORS.2, R61.1, U2.1 (OUT)
INV2_IN: INVERTORS.3, R62.2
INV2_OUT: INVERTORS.4, R63.1, U2.7 (OUT)
INV3_IN: INVERTORS.5, R64.2
INV3_OUT: INVERTORS.6, R65.1, U2.10 (OUT)
INV4_IN: INVERTORS.7, R66.2
INV4_OUT: INVERTORS.8, R67.1, U2.16 (OUT)
KEYPAD_C1: IC1.35 ((A8)PC0), KEYPAD.1
KEYPAD_C2: IC1.36 ((A9)PC1), KEYPAD.2
KEYPAD_C3: IC1.37 ((A10)PC2), KEYPAD.3
KEYPAD_C4: IC1.38 ((A11)PC3), KEYPAD.4
KEYPAD_R1: IC1.39 ((A12)PC4), KEYPAD.5
KEYPAD_R2: IC1.40 ((A13)PC5), KEYPAD.6
KEYPAD_R3: IC1.41 ((A14)PC6), KEYPAD.7
KEYPAD_R4: IC1.42 ((A15)PC7), KEYPAD.8
unnamed: R93.1, R_DIG_PWL.11 (H)
unnamed: OA_LT1365.3, U4.3 (+IN)
unnamed: CFA5.5 (3), S9.5
unnamed: R68.1, R91.2 (S), R91.3 (E), U3.2 (-IN)
unnamed: R69.1, R89.2 (S), R89.3 (E), U3.6 (-IN)
unnamed: CFA5.3 (2), R41.2
unnamed: R41.1, S9.2
unnamed: R70.1, R92.2 (S), R92.3 (E), U3.11 (-IN)
unnamed: OA_LT1365.2, U4.2 (-IN)
unnamed: C107.1, R86.2 (S), U4.5 (+IN)
unnamed: OA_LT1365.1, U4.1 (OUT)
unnamed: R71.1, R90.2 (S), R90.3 (E), U3.15 (-IN)
unnamed: C109.1, R88.2 (S), U4.14 (+IN)
unnamed: R_DIG_IC.9 (IN+), R_DIG_IC.12 (W)
unnamed: IC_OUT.1, IC_OUT.2, IC_OUT.3, IC_OUT.4, R_DIG_IC.7 (OUT), R_DIG_IC.8 (IN-)
unnamed: C108.1, R87.2 (S), U4.12 (+IN)
unnamed: CFA5.11 (5), R93.2
unnamed: JUMPER1.1, JUMPER1.2, JUMPER1.3, JUMPER1.4
unnamed: AD_PWL.5 (REFIN/OUT), C57.1
unnamed: AD_OUT1.5 (REFIN/OUT), C58.1
unnamed: AD_OUT2.5 (REFIN/OUT), C59.1
unnamed: JUMPER2.1, JUMPER2.2, JUMPER2.3, JUMPER2.4
unnamed: JUMPER3.1, JUMPER3.2, JUMPER3.3, JUMPER3.4
unnamed: C80.1, IC2.7 (PB6(XTAL1/TOSC1)), Q2.2
unnamed: C81.1, IC2.8 (PB7(XTAL2/TOSC2)), Q2.1
unnamed: C78.2, IC1.23 (XTAL2), Q1.2
unnamed: C79.2, IC1.24 (XTAL1), Q1.1
unnamed: RDIG1.1, R_DIG_1.11 (H)
unnamed: RDIG1.2, R_DIG_1.12 (W)
unnamed: RDIG2.1, R_DIG_2.11 (H)
unnamed: RDIG2.2, R_DIG_2.12 (W)
unnamed: IC3.8 (USBDP), R56.1
unnamed: IC3.9 (USBDM), R57.1
unnamed: R60.1, R61.2, U2.2 (-IN)
unnamed: R62.1, R63.2, U2.6 (-IN)
unnamed: R66.1, R67.2, U2.15 (-IN)
unnamed: R64.1, R65.2, U2.11 (-IN)
PDI: JP63.3, PROG.4
PDO: JP63.4, PROG.6
PWL_IN: AD_PWL.7 (VIN0), PWL.1, S9.3 (S), S9.4 (O)
PWL_OUT: CFA5.12 (6), PWL.2
PWL_RESET: IC2.29 (PC6(/RESET)), JP62.6, R55.1
RST: JP62.4, PROG.5
SPI_CORE_CS_IC: IC1.29 ((IC1)PD4), R_DIG_IC.3 (!CS!)
SPI_CORE_CS_OUT1: AD_OUT1.1 (!CS!), IC1.30 ((XCK1)PD5)
SPI_CORE_CS_OUT2: AD_OUT2.1 (!CS!), IC1.31 ((T1)PD6)
SPI_CORE_CS_R1: IC1.32 ((T2)PD7), R_DIG_1.3 (!CS!)
SPI_CORE_CS_R2: IC1.14 ((OC0)PB4), R_DIG_2.3 (!CS!)
SPI_CORE_MISO: AD_OUT1.12 (DOUT), AD_OUT2.12 (DOUT), IC1.13 ((MISO)PB3)
SPI_CORE_MOSI: AD_OUT1.2 (DIN), AD_OUT2.2 (DIN), IC1.12 ((MOSI)PB2), R_DIG_1.2 (DIN), R_DIG_2.2 (DIN), R_DIG_IC.2 (DIN)
SPI_CORE_SCLK: AD_OUT1.14 (SCLK), AD_OUT2.14 (SCLK), IC1.11 ((SCK)PB1), JP62.1, R_DIG_1.1 (SCLK), R_DIG_2.1 (SCLK), R_DIG_IC.1 (SCLK)
SPI_PWL_CS_AD: AD_PWL.1 (!CS!), IC2.12 (PB0(ICP))
SPI_PWL_CS_R_DIG: IC2.13 (PB1(OC1A)), R_DIG_PWL.3 (!CS!)
SPI_PWL_MISO: AD_PWL.12 (DOUT), IC2.16 (PB4(MISO)), JP63.6
SPI_PWL_MOSI: AD_PWL.2 (DIN), IC2.15 (PB3(MOSI/OC2)), JP63.5, R_DIG_PWL.2 (DIN)
SPI_PWL_SCLK: AD_PWL.14 (SCLK), IC2.17 (PB5(SCK)), JP62.5, R_DIG_PWL.1 (SCLK)
UART_PC_RX_TX: IC1.2 ((RXD/PDI)PE0), IC3.1 (TXD), JP63.1
UART_PC_TX_RX: IC1.3 ((TXD/PDO)PE1), IC3.4 (RXD), JP63.2
UART_PWL_RX_TX: IC1.27 ((RXD1/INT2)PD2), IC2.31 (PD1(TXD))
UART_PWL_TX_RX: IC1.28 ((TXD1/INT3)PD3), IC2.30 (PD0(RXD))

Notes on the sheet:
ANALOG PART 2, DIGITAL PART
PWL BLOCK
IC BLOCK
DIGITAL PROCESSING
DIGITAL IN/OUT
CONSTANT SOURCES
PROGRAMMER
DIGITAL POTENTIOMETERS
INVERTORS
AMPLIFIERS

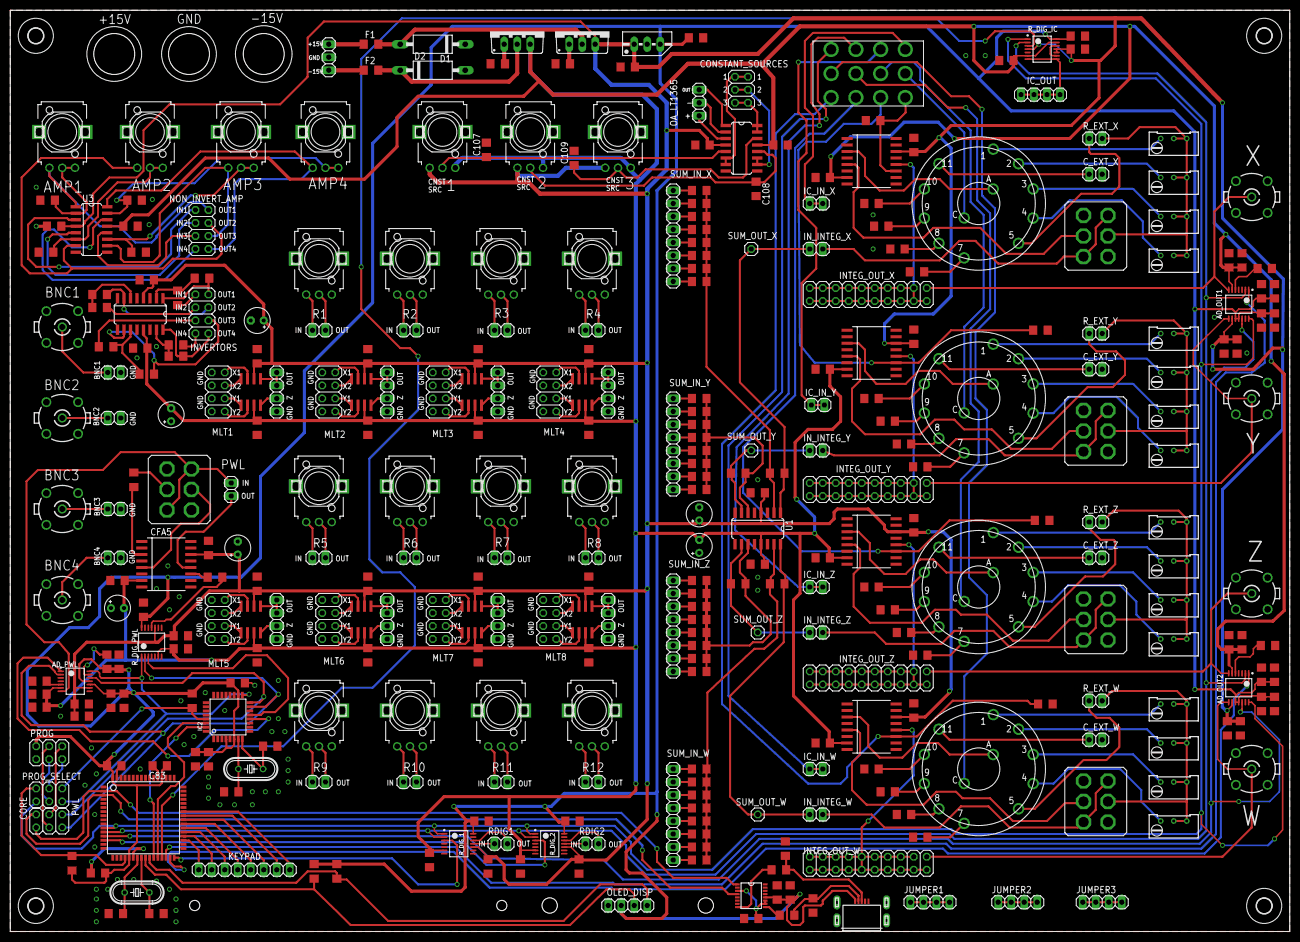
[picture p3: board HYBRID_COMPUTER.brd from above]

Board: 2 copper layers, 250.0 x 180.0 mm, 348 parts (0 on the bottom side), 296 nets.

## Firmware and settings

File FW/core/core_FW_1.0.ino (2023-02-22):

/*
      CORE_FW_1.0

   Author: Miroslav Rujzl

   This code is used for the main MCU of the hybrid computer
   for simulation and modeling of nonlinear dynamic systems.
   It was developed at Department of Radio Electronics,
   Brno University of Technology within the grant Development of
   analog computer with hybrid analog-digital components for
   accurate modeling of chaotic systems. This grant is realised
   within the project Quality Internal Grants of BUT (KInG BUT),
   Reg. No. CZ.02.2.69 / 0.0 / 0.0 / 19_073 / 0016948, which is
   financed from the OP RDE.

   Information about the board (MegaCore):
   - MCU ATMega64
   - External 16MHz crystal
   - BOD 2.7V
   - EEPROM retained
   - LTO disabled
   - No bootloader
   - Arduino as ISP (MegaCore) programmer

   Controlable components:
  ´- Keyboard ADAFRUIT 3844
   - I2C display
   - UART for communication with PC
   - 3x digital potentiometers MAX5437EUD+ (2x counting potentiometers,
     1x for initial conditions settings)
   - 2x AD converters AD7322BRUZ
   - 1x PWL block (communication via UART commands)

*/

// --- Includes ---

#include <Keypad.h>
#include "U8glib.h"
#include <SPI.h>

#include "core_fw_pinout.h"
#include "max5437eud_reg_ctrl.h"
#include "ad7322bruz_reg_ctrl.h"

// --- Defines ---

// UART settings
#define UART_PC_BAUDRATE      115200
#define UART_PWL_BAUDRATE     9600

// Display settings
#define REMOTE_DIS  0
#define REMOTE_EN   1
#define RECORD_DIS  0
#define RECORD_EN   1

// STM defines
#define STM_STATE_INIT    0
#define STM_STATE_MAIN    1
#define STM_STATE_IC      2
#define STM_STATE_RDIG    3
#define STM_STATE_PWL     4
#define STM_STATE_RECORD  5
#define STM_STATE_REMOTE  6

// Remote defines
#define REMOTE_IC         1
#define REMOTE_R1         2
#define REMOTE_R2         3
#define REMOTE_PWL        4
#define REMOTE_RECSTART   5
#define REMOTE_RECSTOP    6     

// --- Typedefs ---

typedef void (*function_p)();

// --- Global variables ---

// Keypad config
const uint8_t   rows = 4;
const uint8_t   columns = 4;
char            keys[rows][columns] = {{'1', '2', '3', 'A'}, {'4', '5', '6', 'B'}, {'7', '8', '9', 'C'}, {'*', '0', '#', 'D'}};
uint8_t         pinrows[rows] = {KEYPAD_R1_PIN, KEYPAD_R2_PIN, KEYPAD_R3_PIN, KEYPAD_R4_PIN};
uint8_t         pincolumns[columns] = {KEYPAD_C1_PIN, KEYPAD_C2_PIN, KEYPAD_C3_PIN, KEYPAD_C4_PIN};

// Keypad variables
Keypad keypad_core = Keypad(makeKeymap(keys), pinrows, pincolumns, rows, columns);
char pressed_key;

// Display variables
U8GLIB_SSD1306_128X64 display_core(U8G_I2C_OPT_NONE);
const int blink_time = 3000;

//UART variables
String uart_pc_rx_buffer;
String uart_pwl_rx_buffer;

//STM variables
uint8_t stm_state = STM_STATE_INIT;

// ADC settings
uint16_t control_reg;
uint16_t range_reg;

// --- Prototypes ---

float mapfloat(float x, float in_min, float in_max, float out_min, float out_max);
void serialFlush(void);
void serial1Flush(void);
void remote(void);
void display_update(function_p func_to_print);
void print_init();
void print_menu();
void print_wrong_key();
void print_pwl();
void print_recstart();
void print_recstop();
void print_nonconnected();
void print_connected();
void print_disconnected();
void rdig_send(uint8_t data_to_send, uint8_t device);
void adc_config(void);
void adc_read(uint8_t device, int16_t * result_0, int16_t * result_1);
void initial_conditions();
void rdig();
void record();

// --- Functions ---

float mapfloat(float x, float in_min, float in_max, float out_min, float out_max)
{
  return (x - in_min) * (out_max - out_min) / (in_max - in_min) + out_min;
}

void serialFlush(void)
{
  while(Serial.available() > 0) 
  {
    char t = Serial.read();
  }
}

void serial1Flush(void)
{
  while(Serial1.available() > 0) 
  {
    char t = Serial1.read();
  }
}

void remote(void)
{
  uint8_t remote_ctrl = REMOTE_DIS;
  uint8_t record_ctrl = RECORD_DIS;
  float   setval      = 0;
  uint8_t spi_val     = 0;
  String  setval_str;

  unsigned long last_rec_time = micros();
  unsigned long period = 20;

  int16_t ad_value[4];

  display_update(print_nonconnected);

  serialFlush();
  
  while(remote_ctrl == REMOTE_DIS)
  {
    if(Serial.available() > 0)
    {
      uart_pc_rx_buffer = Serial.readStringUntil('\n');
    }
    
    if(uart_pc_rx_buffer.equals("CON"))
    {
      Serial.println("OK");
      remote_ctrl = REMOTE_EN;
    }
  }

  display_update(print_connected);

  while(remote_ctrl == REMOTE_EN)
  {
    if(Serial.available() > 0)
    {
      uart_pc_rx_buffer = Serial.readStringUntil('\n');

      if(uart_pc_rx_buffer.substring(0,2) == "IC")
      {
        setval_str = uart_pc_rx_buffer.substring(3);
        setval = setval_str.toFloat();
        setval = constrain(setval,-15,15);
        setval = mapfloat(setval,-15,15,0,127);
        spi_val = (uint8_t)setval;
        rdig_send(spi_val, SPI_CS_RDIG_IC_PIN);
        Serial.println("OK");
      }
      else if(uart_pc_rx_buffer.substring(0,2) == "R1")
      {
        setval_str = uart_pc_rx_buffer.substring(3);
        setval = setval_str.toFloat();
        setval = constrain(setval,0,1);
        setval = mapfloat(setval,0,1,0,127);
        spi_val = (uint8_t)setval;
        rdig_send(spi_val, SPI_CS_RDIG_1_PIN);
        Serial.println("OK");
      }
      else if(uart_pc_rx_buffer.substring(0,2) == "R2")
      {
        setval_str = uart_pc_rx_buffer.substring(3);
        setval = setval_str.toFloat();
        setval = constrain(setval,0,1);
        setval = mapfloat(setval,0,1,0,127);
        spi_val = (uint8_t)setval;
        rdig_send(spi_val, SPI_CS_RDIG_2_PIN);
        Serial.println("OK");  
      }
      else if(uart_pc_rx_buffer.substring(0,3) == "PWL")
      {
        Serial1.println(uart_pc_rx_buffer.substring(3));
        uart_pwl_rx_buffer = Serial1.readStringUntil('\n');

        
      }
      else if(uart_pc_rx_buffer.substring(0,8) == "RECSTART")
      {
        setval_str = uart_pc_rx_buffer.substring(9);
        setval = setval_str.toFloat();
        period = (unsigned long)((1/setval) * 1000000);
        record_ctrl = RECORD_EN;
        //Serial.println(period);
        Serial.println("OK");
        delay(500);
      }
      else if(uart_pc_rx_buffer == "RECSTOP")
      {
        record_ctrl = RECORD_DIS;
        Serial.println("OK");
        delay(500);
      }
      else if(uart_pc_rx_buffer == "DIS")
      {
        remote_ctrl = REMOTE_DIS;
        Serial.println("OK");
      }
    }

    if((record_ctrl == RECORD_EN) && ((micros() - last_rec_time) > period))
    {
      adc_read(SPI_CS_AD_XY_PIN, &ad_value[0], &ad_value[1]);
      adc_read(SPI_CS_AD_ZW_PIN, &ad_value[2], &ad_value[3]);

      Serial.print(ad_value[0]);
      Serial.print(',');
      Serial.print(ad_value[1]);
      Serial.print(',');
      Serial.print(ad_value[2]);
      Serial.print(',');
      Serial.println(ad_value[3]);

      last_rec_time = micros();
    }
  }

  serialFlush();

  display_update(print_disconnected);
  delay(blink_time);
}

void display_update(function_p func_to_print)
{
  display_core.firstPage();
  do {
    func_to_print();
  }while(display_core.nextPage());
}

void print_init()
{
  display_core.setFont(u8g_font_courB14);
  display_core.drawStr(20,15," Hybrid ");
  display_core.drawStr(20,35,"computer");
  display_core.drawStr(30,55," v1.0");  
}

void print_menu()
{
  display_core.setFont(u8g_font_courB10);
  display_core.drawStr(25,13,"Main menu"); 
  display_core.setFont(u8g_font_courR08);
  display_core.drawStr(5,23,"A - set init. cond.");
  display_core.drawStr(5,33,"B - set dig. pot.");
  display_core.drawStr(5,43,"C - PWL block");
  display_core.drawStr(5,53,"D - activate record");
  display_core.drawStr(5,63,"0 - connect with PC");
}

void print_wrong_key()
{
  display_core.setFont(u8g_font_courB10);
  display_core.drawStr(40,25,"Wrong");
  display_core.drawStr(40,40," key");
}

void print_pwl()
{
  display_core.setFont(u8g_font_courB10);
  display_core.drawStr(10,20,"PWL block is");
  display_core.drawStr(10,35,"available in");
  display_core.drawStr(10,50,"  PC app.");
}

void print_recstart()
{
  display_core.setFont(u8g_font_courB08);
  display_core.drawStr(25,10,"Recording");

  display_core.setFont(u8g_font_courB08);
  display_core.setPrintPos(25,30);
  display_core.print("  ACTIVE");

  display_core.setFont(u8g_font_u8glib_4);
  display_core.setPrintPos(5,55);
  display_core.drawStr(5,55,"* - START, # - STOP");
  display_core.drawStr(5,60,"A - back to menu");
}

void print_recstop()
{
  display_core.setFont(u8g_font_courB08);
  display_core.drawStr(25,10,"Recording");
  
  display_core.setFont(u8g_font_courB08);
  display_core.setPrintPos(25,30);
  display_core.print("INACTIVE");

  display_core.setFont(u8g_font_u8glib_4);
  display_core.setPrintPos(5,55);
  display_core.drawStr(5,55,"* - START, # - STOP");
  display_core.drawStr(5,60,"A - back to menu");
}

void print_nonconnected()
{
  display_core.setFont(u8g_font_courB10);
  display_core.drawStr(7,25," Waiting for");
  display_core.drawStr(7,40,"PC response...");
}

void print_connected()
{
  display_core.setFont(u8g_font_courB10);
  display_core.drawStr(20,35,"Connected.");
}

void print_disconnected()
{
  display_core.setFont(u8g_font_courB10);
  display_core.drawStr(10,35,"Disconnected.");
}

void rdig_send(uint8_t data_to_send, uint8_t device)
{
  digitalWrite(device, LOW);
  
  SPI.transfer(data_to_send);
  
  digitalWrite(device, HIGH);
}

void adc_config(void)
{
  control_reg = AD7322_CONTROL_REG_SEL | AD7322_CTRL_ADD0_V1 | AD7322_CTRL_MODE_SINGLE_ENDED
               | AD7322_CTRL_PWRMODE_NORMAL_MODE | AD7322_CTRL_CODING_TWO_COMP | AD7322_CTRL_REF_INT | AD7322_CTRL_SEQ_ENABLE;
  range_reg = AD7322_RANGE_REG_SEL | AD7322_RNGE_V0_BIPOLAR_10V | AD7322_RNGE_V1_BIPOLAR_10V;

  digitalWrite(SPI_CS_AD_XY_PIN, LOW);
//pressed_key = keypad_core.waitForKey();
  SPI.transfer(range_reg);
//pressed_key = keypad_core.waitForKey();
  SPI.transfer(control_reg);
//pressed_key = keypad_core.waitForKey();
  digitalWrite(SPI_CS_AD_XY_PIN, HIGH);
//pressed_key = keypad_core.waitForKey();
  digitalWrite(SPI_CS_AD_ZW_PIN, LOW);
//pressed_key = keypad_core.waitForKey();
  SPI.transfer(range_reg);
//pressed_key = keypad_core.waitForKey();
  SPI.transfer(control_reg);
//pressed_key = keypad_core.waitForKey();
  digitalWrite(SPI_CS_AD_ZW_PIN, HIGH);
//pressed_key = keypad_core.waitForKey();
}

void adc_read(uint8_t device, int16_t * result_0, int16_t * result_1)
{
  uint16_t res_0;
  uint16_t res_1;
  
  digitalWrite(device, LOW);

  res_0 = SPI.transfer(AD7322_NONE_REG_SEL);
  res_1 = SPI.transfer(AD7322_NONE_REG_SEL);

  digitalWrite(device, HIGH);

  *result_0 = (int16_t)(res_0 << 4);
  *result_1 = (int16_t)(res_1 << 4);

  *result_0 = *result_0 / 16;
  *result_0 = *result_1 / 16;
}

void initial_conditions()
{
  bool    quit        = false;
  bool    set         = false;
  float   setval      = 0;
  uint8_t spi_val     = 0;
  String  setval_str;
  char    p_ic        = 0;

  do{

    display_core.firstPage();
    do {
      display_core.setFont(u8g_font_courB08);
      display_core.drawStr(13,10,"Initial conditions");

      display_core.setFont(u8g_font_courR08);
      display_core.setPrintPos(10,30);
      display_core.print("Value: ");
      display_core.setFont(u8g_font_courB08);
      display_core.print(setval_str);
      display_core.print(" V");

      if(set)
      {
        display_core.setFont(u8g_font_courB08);
        display_core.setPrintPos(50,45);
        display_core.print(" SET");
      }
      else
      {
        display_core.setFont(u8g_font_courB08);
        display_core.setPrintPos(50,45);
        display_core.print("UNSET");
      }

      display_core.setFont(u8g_font_u8glib_4);
      display_core.setPrintPos(5,55);
      display_core.drawStr(5,55,"* - set value, # - ., B - clear,");
      display_core.drawStr(5,60,"A - back to menu, D - minus");
     
    }while(display_core.nextPage());

    if(set == true)
    {
      setval_str = String("");
      set = false;
    }

    pressed_key = keypad_core.waitForKey();
    set = false;

    switch(pressed_key)
    {
      case'*':
        set = true;

        setval = setval_str.toFloat();
        setval = constrain(setval,-15,15);
        setval_str = String(setval, 3);
        setval = mapfloat(setval,-15,15,0,127);
        spi_val = (uint8_t)setval;

        rdig_send(spi_val, SPI_CS_RDIG_IC_PIN);
      break;

      case'#':
        setval_str = String(setval_str + '.');
      break;

      case'A':
        quit = true;
      break;

      case'B':
        setval_str = String("");
      break;
      
      case'C':
        display_update(print_wrong_key);
        delay(blink_time);
      break;
      
      case'D':
        setval_str = String('-' + setval_str); 
      break;

      default:
        setval_str = String(setval_str + pressed_key);
      break;
    }
    
  }while(!quit);
}

void rdig()
{
  bool    quit        = false;
  bool    set         = false;
  float   setval      = 0;
  uint8_t spi_val     = 0;
  String  setval_str;
  char    p_setval    = 0;
  uint8_t choose_pot  = 0;
  uint8_t choose_pot_print  = 0;

  do {

    display_core.firstPage();
    do {
      display_core.setFont(u8g_font_courB08);
      display_core.setPrintPos(10,10);
      display_core.print("Dig. potentiometer");
      display_core.print("s");

      display_core.setFont(u8g_font_courR08);
      display_core.drawStr(25,25,"  Select the");
      display_core.drawStr(25,35,"potentiometer:");
      display_core.drawStr(5,50,"A - RDIG1");
      display_core.drawStr(70,50,"B - RDIG2");
      
    }while(display_core.nextPage());

    pressed_key = keypad_core.waitForKey();

    if(pressed_key == 'A')
    {
      choose_pot = SPI_CS_RDIG_1_PIN;
      choose_pot_print  = 1;
      quit = true;
    }
    else if(pressed_key == 'B')
    {
      choose_pot = SPI_CS_RDIG_2_PIN;
      choose_pot_print  = 2;
      quit = true;
    }
    else
    {
      display_update(print_wrong_key);
      delay(blink_time);
    }
  }while(!quit);

  quit = false;

  do{

    display_core.firstPage();
    do{
      display_core.setFont(u8g_font_courB08);
      display_core.setPrintPos(7,10);
      display_core.print("Dig. potentiometer");
      display_core.print(" ");
      display_core.print(choose_pot_print);
      

      display_core.setFont(u8g_font_courR08);
      display_core.setPrintPos(10,30);
      display_core.print("Value: ");
      display_core.setFont(u8g_font_courB08);
      display_core.print(setval_str);
      
      if(set)
      {
        display_core.setFont(u8g_font_courB08);
        display_core.setPrintPos(50,45);
        display_core.print(" SET");
      }
      else
      {
        display_core.setFont(u8g_font_courB08);
        display_core.setPrintPos(50,45);
        display_core.print("UNSET");
      }

      display_core.setFont(u8g_font_u8glib_4);
      display_core.setPrintPos(5,55);
      display_core.drawStr(5,55,"* - set value, # - ., B - clear,");
      display_core.drawStr(5,60,"A - back to menu, D - minus");
     
    }while(display_core.nextPage());

    if(set == true)
    {
      setval_str = String("");
      set = false;
    }

    pressed_key = keypad_core.waitForKey();
    set = false;

    switch(pressed_key)
    {
      case'*':
        set = true;

        setval = setval_str.toFloat();
        setval = constrain(setval,0,1);
        setval_str = String(setval, 3);
        setval = mapfloat(setval,0,1,0,127);
        spi_val = (uint8_t)setval;

        rdig_send(spi_val, choose_pot);
      break;

      case'#':
        setval_str = String(setval_str + '.');
      break;

      case'A':
        quit = true;
      break;

      case'B':
        setval_str = String("");
      break;
      
      case'C':
        display_update(print_wrong_key);
        delay(blink_time);
      break;
      
      case'D':
        setval_str = String('-' + setval_str); 
      break;

      default:
        setval_str = String(setval_str + pressed_key);
      break;
    }
    
  }while(!quit);
}

void record()
{
  bool quit = false;
  bool set = false;
  int16_t ad_value[4];

  unsigned long last_rec_time = micros();
  
  display_update(print_recstop);

  while(!quit)
  {
    pressed_key = keypad_core.getKey();

    if(pressed_key != NO_KEY)
    {
      if(pressed_key == '*')
      {
        set = true;
        display_update(print_recstart);
      }
      else if(pressed_key == '#')
      {
        set = false;
        display_update(print_recstop);
      }
      else if(pressed_key == 'A')
      {
        set = false;
        quit = true;
      }
    }

    if(set && ((micros() - last_rec_time) > 20))
    {
      adc_read(SPI_CS_AD_XY_PIN, &ad_value[0], &ad_value[1]);
      adc_read(SPI_CS_AD_ZW_PIN, &ad_value[2], &ad_value[3]);

      Serial.print(ad_value[0]);
      Serial.print(',');
      Serial.print(ad_value[1]);
      Serial.print(',');
      Serial.print(ad_value[2]);
      Serial.print(',');
      Serial.println(ad_value[3]);

      last_rec_time = micros();
    }
  }
}

void setup()
{
  display_update(print_init);
  
  Serial.begin(UART_PC_BAUDRATE);
  //Serial1.begin(UART_PWL_BAUDRATE);

  Serial.setTimeout(1000);
  //Serial1.setTimeout(1000);

  serialFlush();
  //serial1Flush();

  SPI.begin();

  pinMode(SPI_CS_RDIG_IC_PIN, OUTPUT);
  pinMode(SPI_CS_RDIG_1_PIN,  OUTPUT);
  pinMode(SPI_CS_RDIG_2_PIN,  OUTPUT);
  pinMode(SPI_CS_AD_XY_PIN,   OUTPUT);
  pinMode(SPI_CS_AD_ZW_PIN,   OUTPUT);

  digitalWrite(SPI_CS_RDIG_IC_PIN,  HIGH);
  digitalWrite(SPI_CS_RDIG_1_PIN,   HIGH);
  digitalWrite(SPI_CS_RDIG_2_PIN,   HIGH);
  digitalWrite(SPI_CS_AD_XY_PIN,    HIGH);
  digitalWrite(SPI_CS_AD_ZW_PIN,    HIGH);

  adc_config();

  stm_state = STM_STATE_INIT;
}

void loop()
{  
  switch (stm_state)
  {
    case STM_STATE_INIT:
      
      /*do
      {
        if(Serial1.available() > 0)
        {
          uart_pwl_rx_buffer = Serial1.readStringUntil(';');
        } 
      }while(!uart_pwl_rx_buffer.equals("PWL_OK;"));*/

      delay(blink_time);

      stm_state = STM_STATE_MAIN;

    break;

    case STM_STATE_MAIN:

      display_update(print_menu);

      pressed_key = keypad_core.waitForKey();

      switch(pressed_key)
      {
        case 'A':
          stm_state = STM_STATE_IC;
        break;

        case 'B':
          stm_state = STM_STATE_RDIG;
        break;

        case 'C':
          stm_state = STM_STATE_PWL;
        break;

        case 'D':
          stm_state = STM_STATE_RECORD;
        break;

        case '0':
          stm_state = STM_STATE_REMOTE;
        break;

        default:
          display_update(print_wrong_key);
          delay(blink_time);
        break;
      }

    break;

    case STM_STATE_IC:
      initial_conditions();
      stm_state = STM_STATE_MAIN;
    break;

    case STM_STATE_RDIG:
      rdig();
      stm_state = STM_STATE_MAIN;
    break;

    case STM_STATE_PWL:
      display_update(print_pwl);
      delay(blink_time);
      stm_state = STM_STATE_MAIN;
    break;

    case STM_STATE_RECORD:
      record();
      stm_state = STM_STATE_MAIN;
    break;
    
    case STM_STATE_REMOTE:
      remote();      
      stm_state = STM_STATE_MAIN;
    break;

    default:

    break;
  }
}

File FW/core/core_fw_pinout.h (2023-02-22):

/*
 * core_fw_pinout.h
 *
 * Created: 16.10.2022
 *  Author: Miroslav Rujzl
 */ 


#ifndef CORE_FW_PINOUT_H_
#define CORE_FW_PINOUT_H_

// PINOUT
#define UART_PC_RX_PIN        0
#define UART_PC_TX_PIN        1
#define UART_PWL_RX_PIN       20
#define UART_PWL_TX_PIN       21

#define I2C_SDA_PIN           18
#define I2C_SDA_PIN           19

#define SPI_SCLK_PIN          9
#define SPI_MOSI_PIN          10
#define SPI_MISO_PIN          11
#define SPI_CS_RDIG_IC_PIN    22
#define SPI_CS_AD_XY_PIN      23
#define SPI_CS_AD_ZW_PIN      24
#define SPI_CS_RDIG_1_PIN     25
#define SPI_CS_RDIG_2_PIN     12

#define KEYPAD_R1_PIN         32
#define KEYPAD_R2_PIN         33
#define KEYPAD_R3_PIN         34
#define KEYPAD_R4_PIN         35
#define KEYPAD_C1_PIN         28
#define KEYPAD_C2_PIN         29
#define KEYPAD_C3_PIN         30
#define KEYPAD_C4_PIN         31

#endif /* CORE_FW_PINOUT_H_ */

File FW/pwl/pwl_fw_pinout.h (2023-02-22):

/*
 * pwl_fw_pinout.h
 *
 * Created: 16.10.2022
 *  Author: Miroslav Rujzl
 */ 


#ifndef PWL_FW_PINOUT_H_
#define PWL_FW_PINOUT_H_

// PINOUT
#define UART_CORE_RX_PIN       0
#define UART_CORE_TX_PIN       1

#define SPI_SCLK_PIN           13
#define SPI_MOSI_PIN           11
#define SPI_MISO_PIN           12
#define SPI_CS_RDIG_PWL_PIN    9
#define SPI_CS_AD_PWL_PIN      8

#endif /* PWL_FW_PINOUT_H_ */
